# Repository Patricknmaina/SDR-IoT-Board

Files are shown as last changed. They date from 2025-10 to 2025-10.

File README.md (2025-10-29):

# SDR‑IoT‑Board

An IoT-based edge device and ground-station platform designed for telemetry and mission data—integrated with a 1U nanosatellite workflow. The hardware centers on an ESP32‑S3 module with LoRa, microSD storage, battery management/charging, sensor interfaces, and multiple expansion headers for rapid prototyping and deployment.

<p align="center">
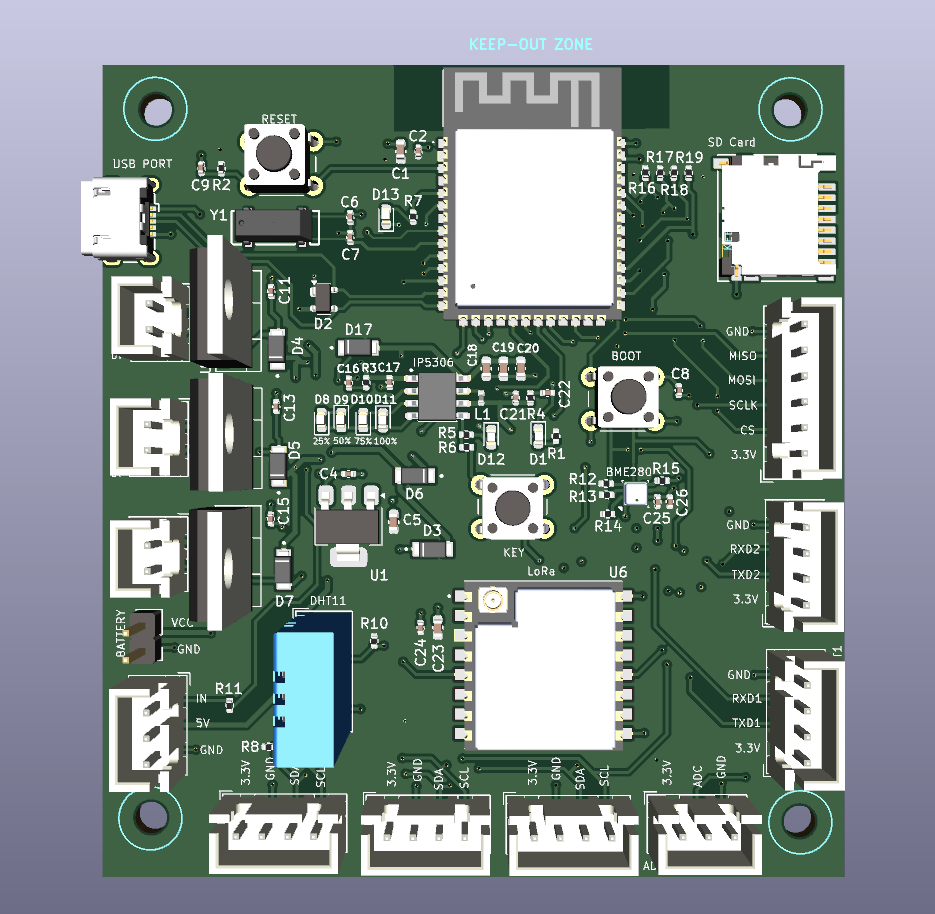
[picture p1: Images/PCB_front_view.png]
PCB Front
  
  <br/>
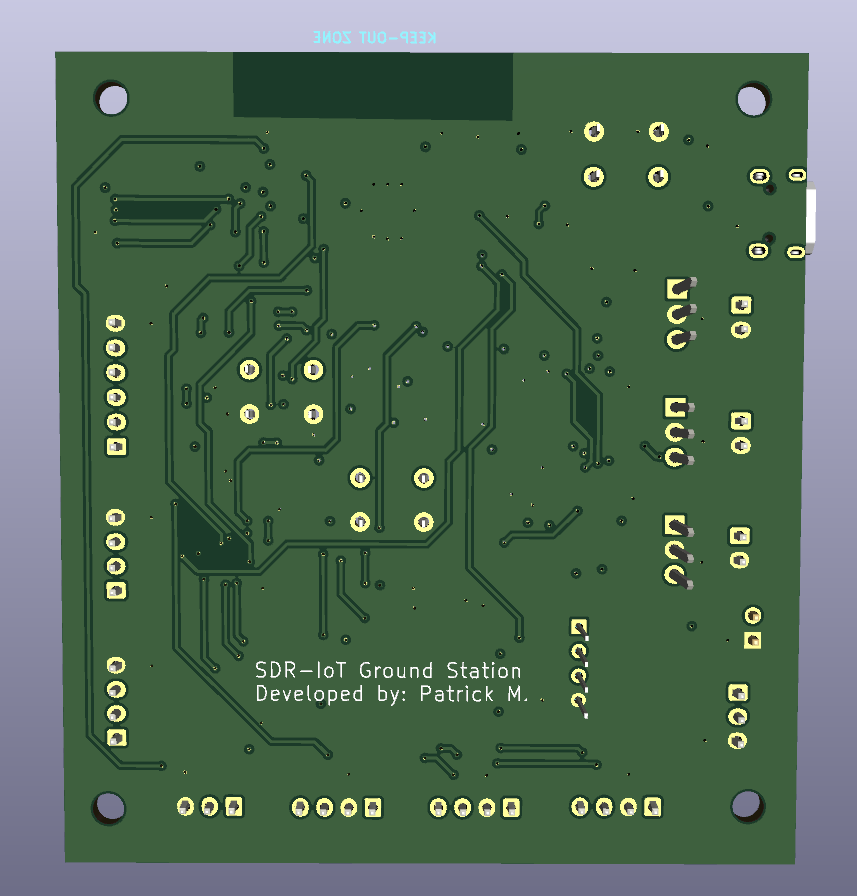
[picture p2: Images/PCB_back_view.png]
PCB Back
  
  <br/>
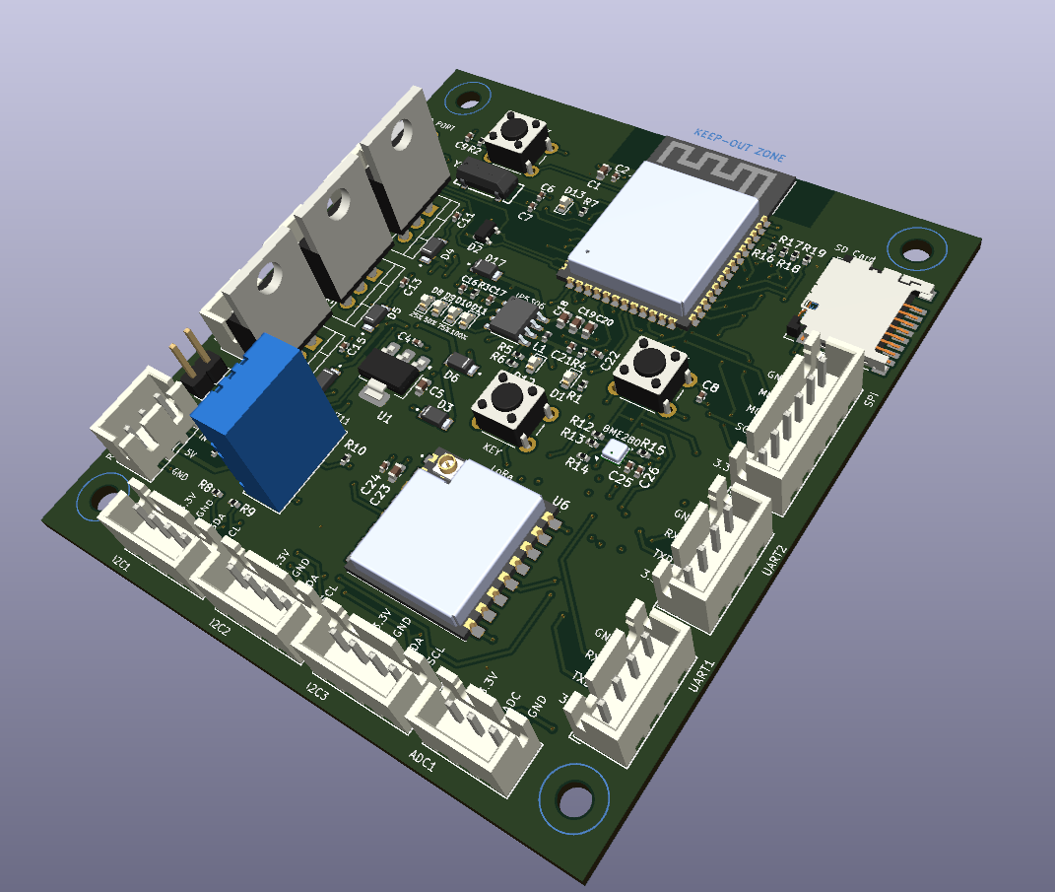
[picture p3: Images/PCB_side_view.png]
PCB Side
  
  <br/>
</p>

## Table of Contents

- Overview
- Key Features
- Hardware Architecture
- Power Architecture
- Interfaces and Connectors
- Major Components
- Project Structure
- Manufacturing (Gerbers, BOM, CPL)
- Bring‑Up Checklist
- Firmware Getting Started
- Mechanical and 3D Models
- License
- Acknowledgements and Notes

## Overview

This repository contains the complete KiCad design for the IoT Edge Device v1.0, including schematic, PCB layout, fabrication outputs, custom footprints, and mechanical models. No firmware is included in this repository; the board is intended to be programmed using the ESP32‑S3’s native USB interface (ESP‑IDF or Arduino‑ESP32).

Use cases include ground-station telemetry collection, environmental sensing, edge data logging, and LoRa-based long-range links to remote nodes or satellite payload testbeds.

## Key Features

- ESP32‑S3‑WROOM‑1‑N16R8 module (16 MB flash, 8 MB PSRAM)
- LoRa radio module (Ai‑Thinker RA‑02, SPI interface)
- microSD storage (SPI mode selected; design notes on SPI vs. SDIO)
- Environmental sensing: BME280 (I2C; default address 0x76), DHT11 header
- Multiple I2C expansion headers for quick peripheral add‑ons
- Two UART headers for serial peripherals and diagnostics
- Relay driver header (external 5 V relay module), driven via ESP32‑S3 GPIO6 through 1 kΩ
- Native USB (Micro‑B) with ESD protection for data and power
- Battery management/boost via IP5306 module; status LEDs for charge/level
- 3.3 V rail via AMS1117‑3.3 LDO
- 32.768 kHz RTC crystal for ESP32‑S3 (ESR ≤ 70 kΩ per note)

## Hardware Architecture

- Microcontroller: ESP32‑S3‑WROOM‑1‑N16R8 (`IoT Edge Device v1.0/IoT Edge Device V1.kicad_sch`)
- Radio: RA‑02 LoRa (SPI: `MOSI_LORA`, `MISO_LORA`, `SCLK_LORA`, `CS_LORA`)
- Storage: microSD (SPI: `MOSI_SD`, `MISO_SD`, `SCLK_SD`, `CS_SD`)
- Sensors: BME280 on I2C (SDO pulled Low → default 0x76), DHT11 via single‑wire `DHT_DATA` header
- Expansion: three I2C headers (`SCL_OUT`, `SDA_OUT`), SPI header, UART1/2 headers
- Control: Relay header driven from ESP32‑S3 GPIO6 via 1 kΩ current‑limit resistor
- Clocking: 32.768 kHz crystal for RTC; ensure ESR ≤ 70 kΩ
- Protection: SP05xxx ESD array on USB; Schottky diodes for power ORing

Notes
- Design text documents the choice of SPI over SDIO for simplicity (SDIO is faster but higher complexity/CPU tradeoffs).
- Exact ESP32 GPIO mappings for the above nets are defined in the schematic; see the KiCad file for authoritative pinout and update firmware pin definitions accordingly.

## Power Architecture

- Sources: 5 V via USB Micro‑B and from IP5306 boost output; diode‑OR prevents back‑feeding.
- Solar input: 12 V panel → external LM7805 module → 5 V for IP5306 input (see design note). For higher efficiency and thermal margin, a buck regulator is recommended over linear.
- Battery: IP5306 manages charging and provides 5 V output; LED indicators for charge and capacity.
- 3.3 V rail: AMS1117‑3.3 LDO powers ESP32‑S3, LoRa, and sensors.

Recommendations
- Consider replacing the 12 V→5 V LM7805 path with a high‑efficiency buck (e.g., LM2596/MP1584) to reduce heat and increase battery/runtime performance.
- Validate 3.3 V load headroom (ESP32‑S3 + LoRa TX + SD activity) and thermal dissipation for the LDO.

## Interfaces and Connectors

- USB: Micro‑B connector; native ESP32‑S3 USB (D+ / D−) for flashing and CDC; ESD protection present.
- I2C: labeled I2C1 / I2C2 / I2C3 headers on `SCL_OUT` and `SDA_OUT` nets.
- SPI: dedicated header labeled “SPI Connector”.
- UART: UART1 and UART2 headers; UART2 noted for DAC use case.
- Relay: external 5 V relay module header; controlled by ESP32‑S3 GPIO6 via 1 kΩ series resistor.
- SD Card: microSD socket (SPI wiring).
- LoRa: RA‑02 module (SPI wiring with dedicated CS).

## Major Components

- X1: ESP32‑S3‑WROOM‑1‑N16R8 (MCU + Wi‑Fi/BLE, native USB)
- U6: Ai‑Thinker RA‑02 LoRa module (SPI)
- J15: microSD socket (Hirose DM3D‑SF)
- U8: BME280 environmental sensor (I2C, default 0x76)
- DHT11: external module via header (`DHT_DATA`)
- U5: IP5306 battery charger/boost controller
- U1: AMS1117‑3.3 linear regulator
- J1: USB Micro‑B connector
- D2: SP05xxx ESD protection for USB
- D4–D7: DFLS130L‑7 Schottky diodes (power ORing)
- Y1: 32.768 kHz crystal for RTC

See `IoT Edge Device v1.0/Fab Files/IoT BOM.csv` for the full sourced BOM (with JLCPCB part numbers) and `IoT Edge Device v1.0/Fab Files/IoT CPL.csv` for centroid/placements.

## Project Structure

- `IoT Edge Device v1.0/` — KiCad project (schematic, PCB, project metadata)
  - `IoT Edge Device V1.kicad_sch` — Schematic
  - `IoT Edge Device V1.kicad_pcb` — PCB layout
  - `Fab Files/` — Gerbers, drill, BOM, CPL for fabrication and assembly
  - `Fabrication Outputs.zip` — Consolidated fab package
- `Design Resources/` — Custom footprints and STEP models
- `Images/` — Renders and module screenshots used in this README

## Manufacturing (Gerbers, BOM, CPL)

All files required for fab and assembly are provided:

1) Gerbers and Drill
- Path: `IoT Edge Device v1.0/Fab Files/*gbr`, `.../IoT Edge Device V1.drl`

2) Bill of Materials
- Path: `IoT Edge Device v1.0/Fab Files/IoT BOM.csv` (includes JLCPCB part numbers)

3) Pick & Place (Centroid)
- Path: `IoT Edge Device v1.0/Fab Files/IoT CPL.csv` (Top placements)

## Firmware Getting Started

- Toolchains: ESP‑IDF (v5.x) or Arduino‑ESP32 with S3 support
- Transport: Native USB (CDC) for flashing and serial output
- Pin definitions: Map nets from the schematic to firmware pins:
  - LoRa SPI: `MOSI_LORA`, `MISO_LORA`, `SCLK_LORA`, `CS_LORA`
  - SD SPI: `MOSI_SD`, `MISO_SD`, `SCLK_SD`, `CS_SD`
  - I2C: `SDA_OUT`, `SCL_OUT`
  - DHT11: `DHT_DATA`
  - Relay: `GPIO6`

Since the ESP32 GPIO numbers tied to these nets can vary by routing, use the KiCad schematic (`.kicad_sch`) as the source of truth and set your firmware `gpio_num_t` values accordingly.

Libraries
- LoRa: `arduino-lmic` or `RadioLib` (Arduino), or ESP‑IDF SPI drivers with Semtech HAL equivalents
- microSD: `SD`/`SdFat` (Arduino) or ESP‑IDF `sdspi_host`
- BME280: Adafruit/ESP‑IDF drivers (I2C)
- DHT11: Adafruit (Arduino) or a simple single‑wire driver

## Mechanical and 3D Models

- STEP models for key parts are under `Design Resources/STEP Files/` (ESP32‑S3 module, RA‑02, IP5306, microSD, crystal, etc.)
- Use these for enclosure fit, heatsinking studies, and cable clearance.

## License

This project is released under the MIT License. See `LICENSE` for details.

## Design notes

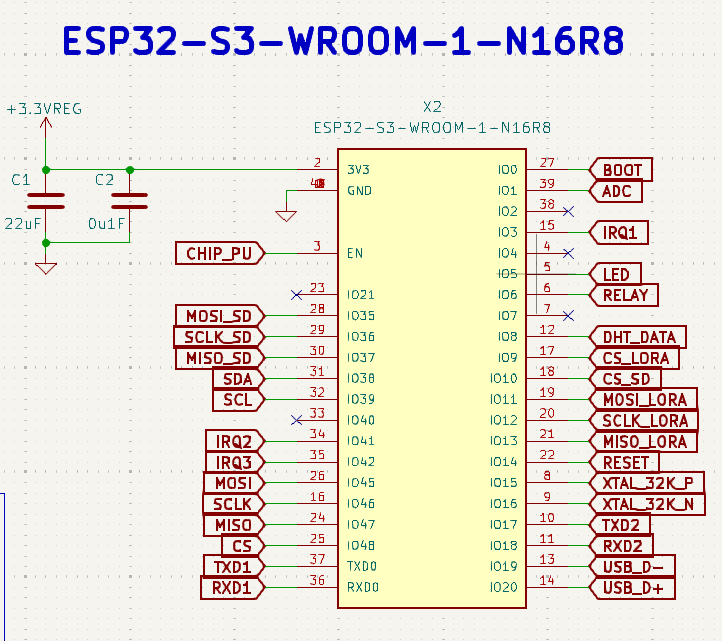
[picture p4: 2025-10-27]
Images/ESP32-S3_module.png

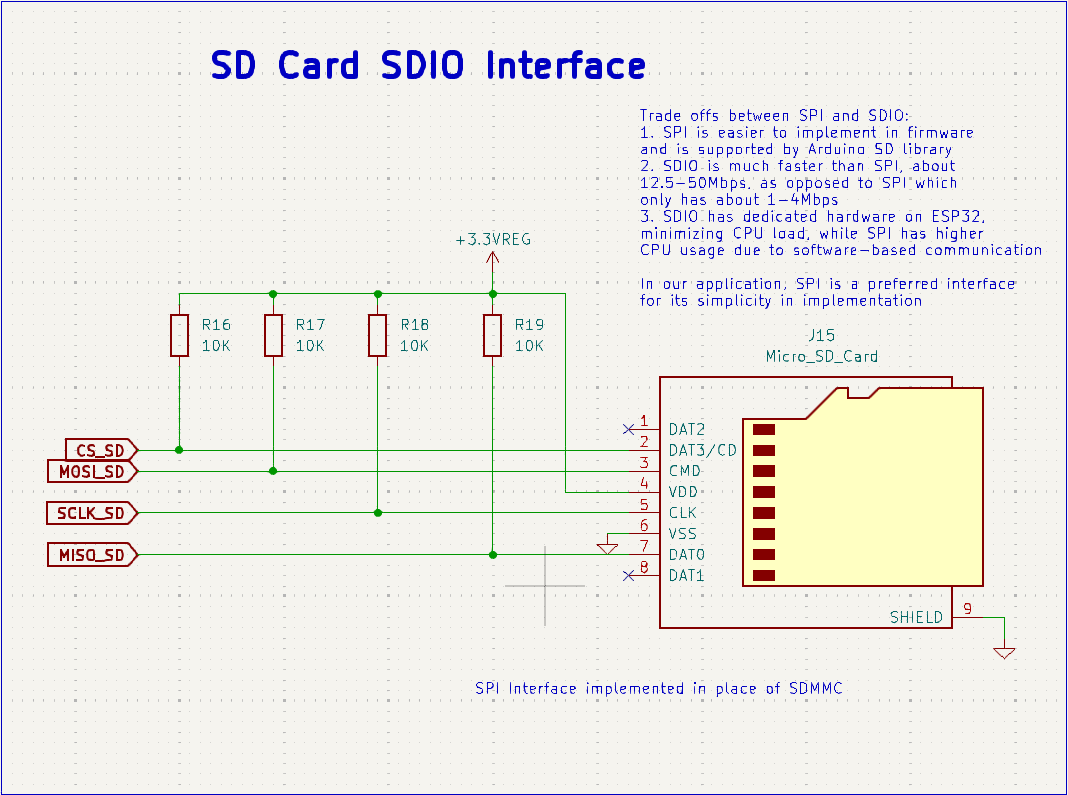
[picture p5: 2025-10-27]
Images/SD-Card_module.png

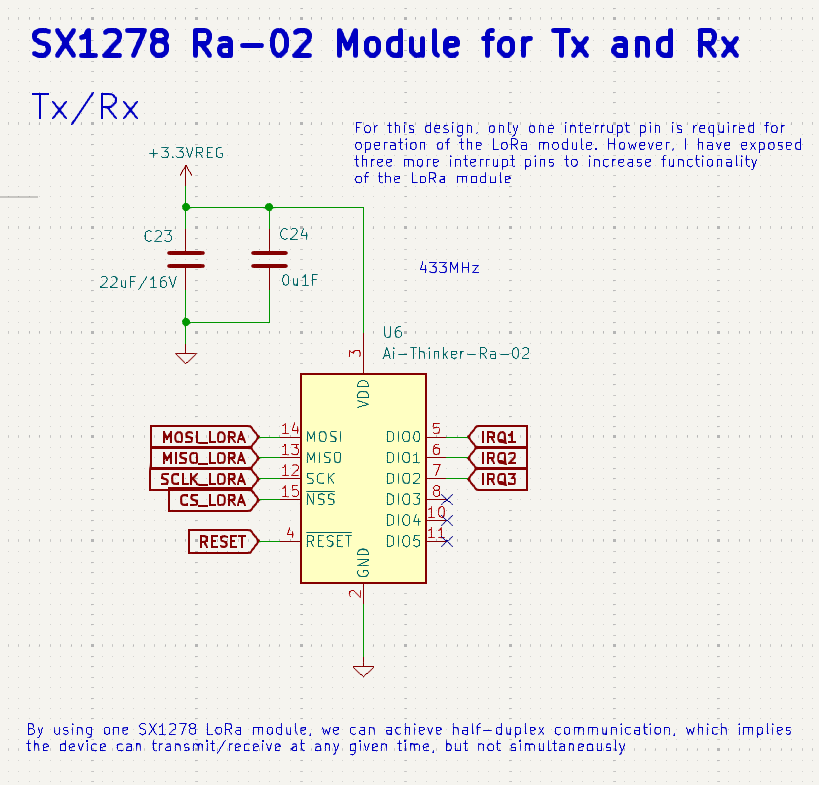
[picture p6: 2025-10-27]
Images/lora_module.png

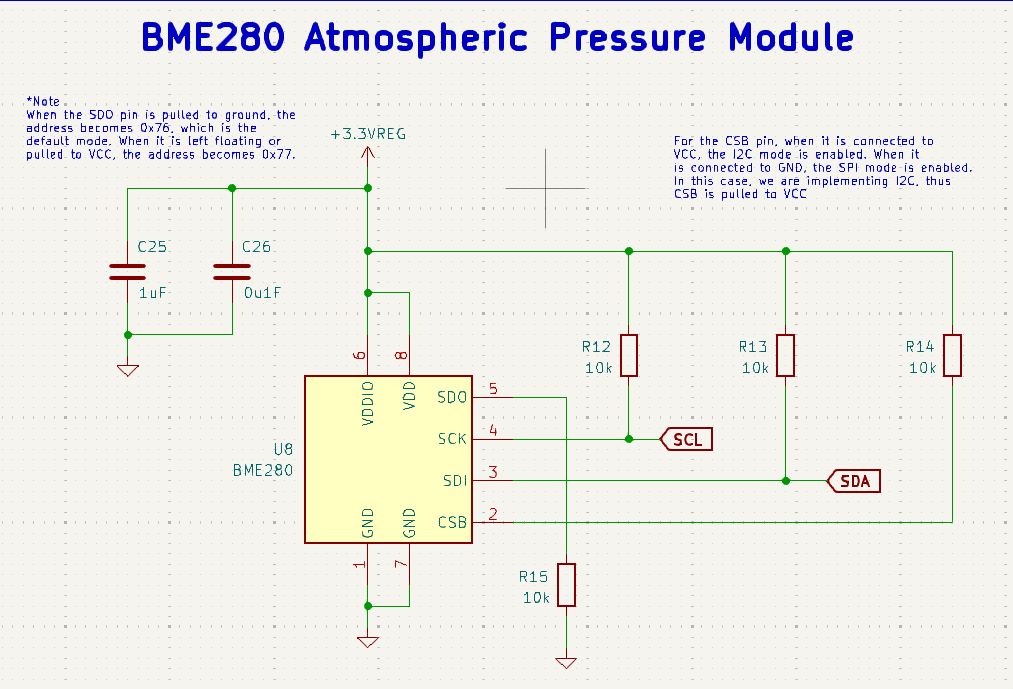
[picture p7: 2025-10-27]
Images/BME280_module.png

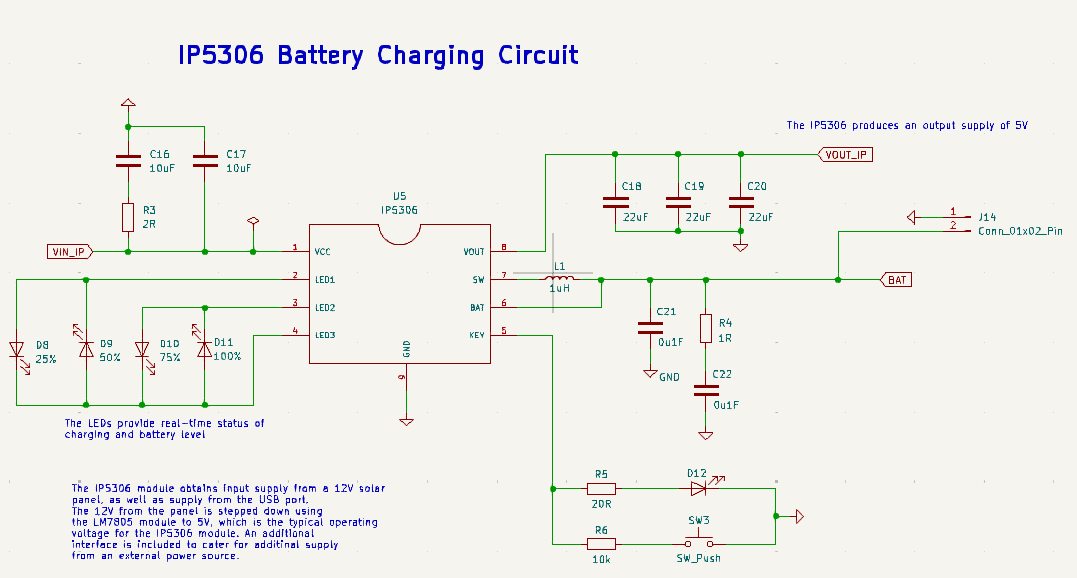
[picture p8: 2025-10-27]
Images/IP5306_module.png

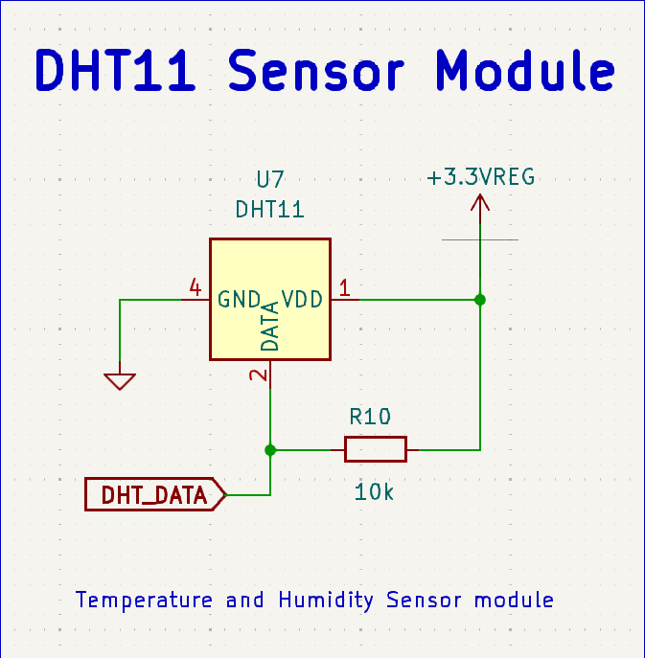
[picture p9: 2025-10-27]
Images/DHT11_module.png

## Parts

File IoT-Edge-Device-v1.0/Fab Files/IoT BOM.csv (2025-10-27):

Comment | Designator | Footprint | JLCPCB Part #
22uF Unpolarized capacitor | C1,C5,C18,C19,C20 | Capacitor_SMD:C_0603_1608Metric | C59461
0.1uF Unpolarized capacitor | C2,C8,C9,C11,C13,C15,C21,C22,C24,C26 | Capacitor_SMD:C_0402_1005Metric | C14663
1uF Unpolarized capacitor | C3,C25 | Capacitor_SMD:C_0402_1005Metric | C15849
10uF Unpolarized capacitor | C4,C16,C17 | Capacitor_SMD:C_0402_1005Metric | C19702
10pF Unpolarized capacitor | C6,C7 | Capacitor_SMD:C_0402_1005Metric | C1634
0.33uF Unpolarized capacitor | C10,C12,C14 | Capacitor_SMD:C_0402_1005Metric | C3039642
22uF/16V Unpolarized capacitor | C23 | Capacitor_SMD:C_0603_1608Metric | C5116073
Red Power Light emitting diode (LED) | D1 | LED_SMD:LED_0603_1608Metric | C965799
Blue IP5306 Key Status LED | D12 | LED_SMD:LED_0603_1608Metric | C965807
Green Status LED | D13 | LED_SMD:LED_0603_1608Metric | C22371297
SP0503BAHT TVS Diode Array, 5.5V Standoff, 3 Channels, SOT-143 package | D2 | Package_TO_SOT_SMD:SOT-143 | C7074
DFLS130L-7 | D4,D5,D6,D7 | DFLS130L-7:DIO_DFLS130L-7 | C110493
25%, 50%, 75% Light emitting diode (Red) | D8, D9, D10 | LED_SMD:LED_0603_1608Metric | C965799
100% Light emitting diode (Green) | D11 | LED_SMD:LED_0603_1608Metric | C22371297
1000V 1A General Purpose Rectifier Diode, DO-41 | D14 | Diode_SMD:D_0603_1608Metric | C727081
Relay Green Status LED | D15 | LED_SMD:LED_0603_1608Metric | C22371297
Relay Red Power LED | D16 | LED_SMD:LED_0603_1608Metric | C965799
USB Micro Type B connector | J1 | Connector_USB:USB_Micro-B_Wuerth_629105150521 | C2894326
Micro SD Card Socket | J15 | Connector_Card:microSD_HC_Hirose_DM3D-SF | C719027
1uH Inductor | L1 | Inductor_SMD:L_0402_1005Metric | C531288
1k Resistor | R1,R4,R5,R15,R16,R17,R18 | Resistor_SMD:R_0402_1005Metric | C11702
10k Resistor | R2,R3,R9,R10,R11,R12,R13,R14,R19,R20,R21,R22 | Resistor_SMD:R_0402_1005Metric | C25744
2R Resistor | R6 | Resistor_SMD:R_0402_1005Metric | C2906922
1R Resistor | R7 | Resistor_SMD:R_0402_1005Metric | C137904
20R Resistor | R8 | Resistor_SMD:R_0402_1005Metric | C310214
1A Low Dropout regulator, positive, 3.3V fixed output, SOT-223 (AMS1117-3.3) | U1 | Package_TO_SOT_SMD:SOT-223-3_TabPin2 | C347222
Ai-Thinker Ra-02 410-525 MHz LoRa Module, SPI interface, U.FL antenna connector | U6 | RA-02_LORA:MODULE_RA-02_LORA | C90039
3-in-1 sensor, humidity, pressure, temperature, I2C and SPI interface, 1.71-3.6V, LGA-8 (BME280) | U8 | Package_LGA:Bosch_LGA-8_2.5x2.5mm_P0.65mm_ClockwisePinNumbering | C92489
IP5306 | U5 | IP5306:SOIC9P127_490X600X170L84X42T330X241N | C181692
ESP32-S3-WROOM-1-N16R8 Module | X1 | ESP32-S3-WROOM-1-N16R8:ESP32S3WROOM1N8R2 | C2913202
WE-XTAL-85SMX Crystal Oscillator | Y1 | WE-XTAL_85SMX:WE-XTAL_85SMX | N/A

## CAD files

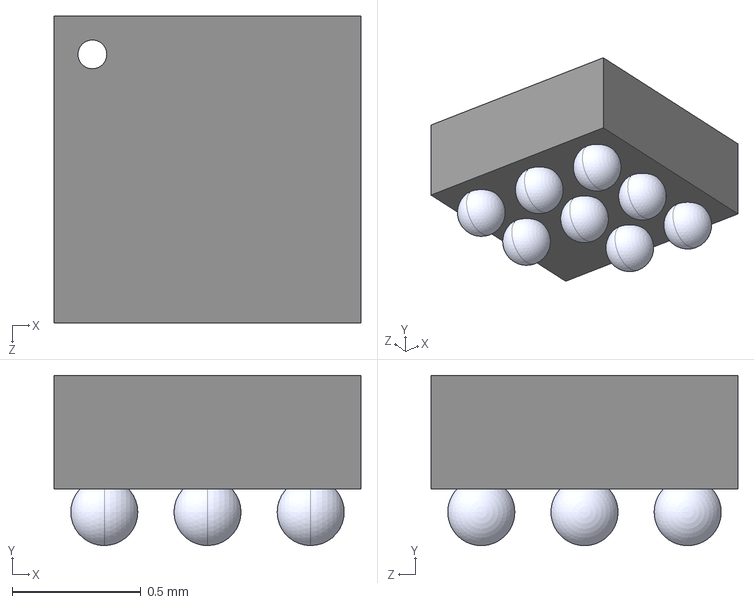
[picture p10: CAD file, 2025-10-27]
Design Resources/Footprints/IP5306/IP5306.step
1.19 x 0.66 x 1.19 mm

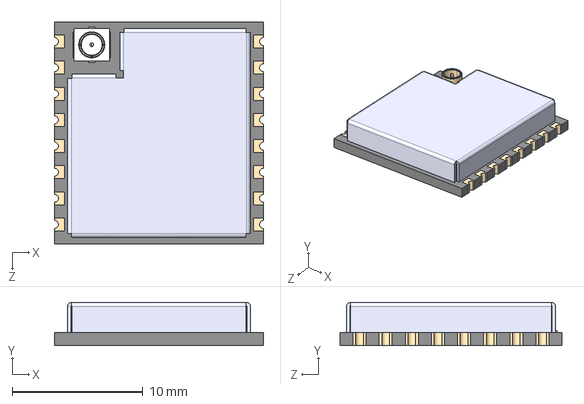
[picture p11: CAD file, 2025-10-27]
Design Resources/STEP Files/RA-02_LORA.step
16.0 x 3.30 x 17.0 mm

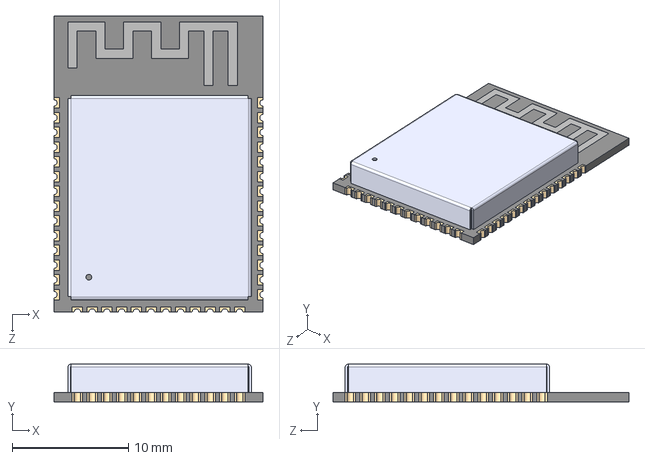
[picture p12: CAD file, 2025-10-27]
Design Resources/STEP Files/ESP32-S3-WROOM-1-N16R8.step
18.0 x 3.25 x 25.5 mm

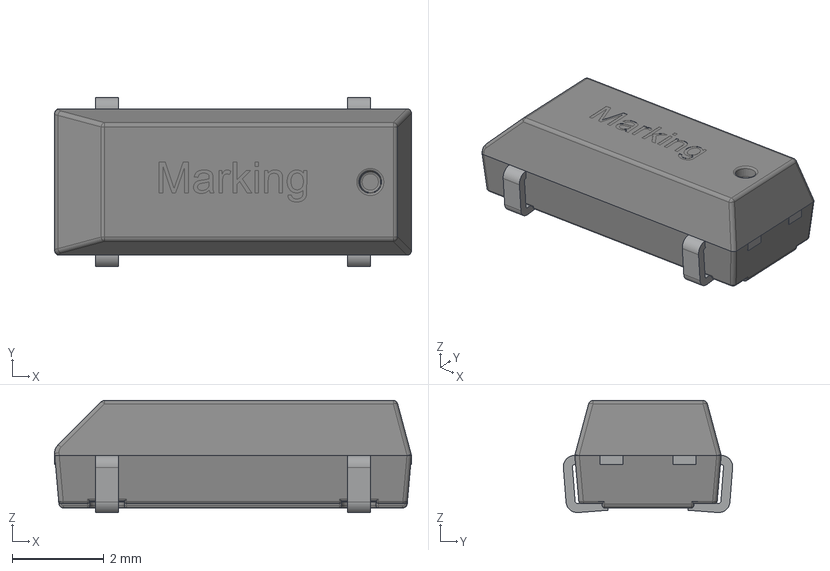
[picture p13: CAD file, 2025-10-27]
Design Resources/STEP Files/WE-XTAL_85SMX.step
7.80 x 3.70 x 2.45 mm
Base
TopCover
Pin

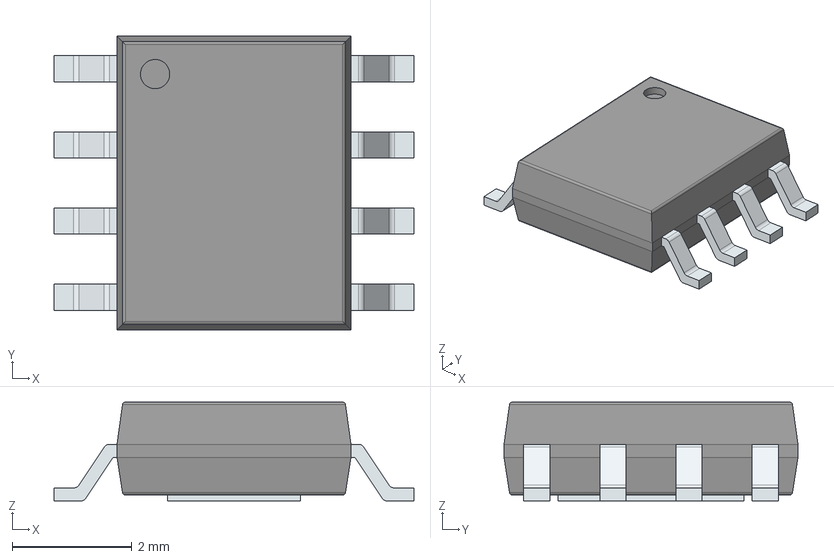
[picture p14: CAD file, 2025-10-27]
Design Resources/STEP Files/IP5306.stp
6.00 x 4.90 x 1.65 mm
PinsArrayLR
ThermalPad

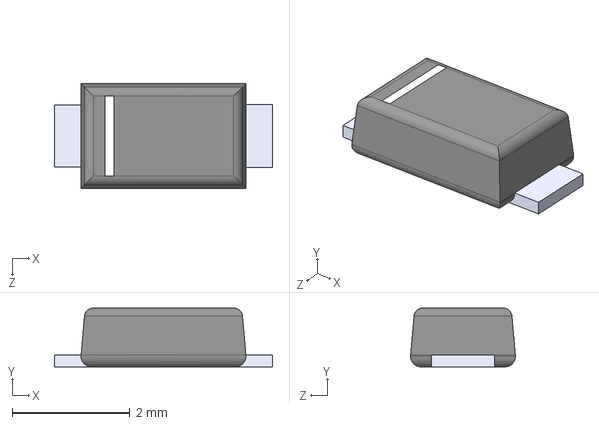
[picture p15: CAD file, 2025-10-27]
Design Resources/STEP Files/DFLS130L-7.step
3.70 x 1.00 x 1.78 mm

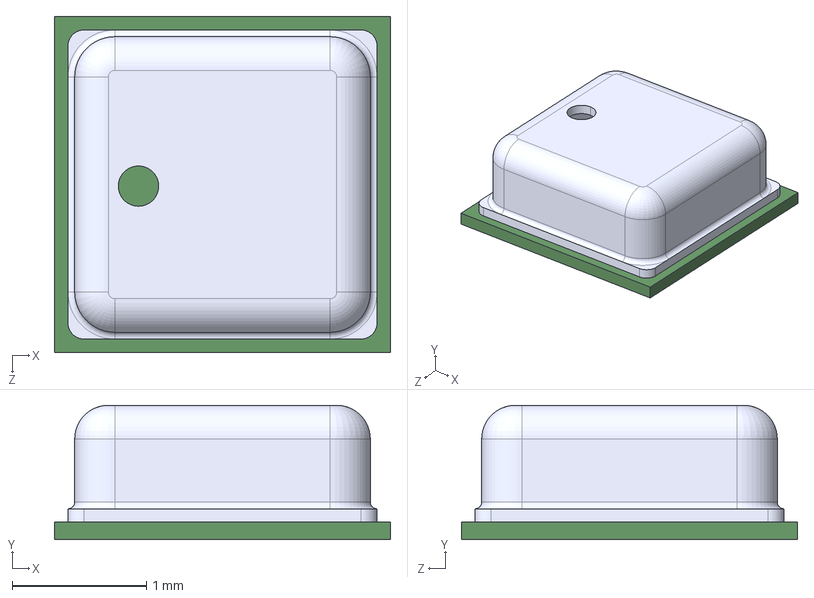
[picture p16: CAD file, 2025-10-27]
Design Resources/STEP Files/BME280--3DModel-STEP-56544.STEP
2.50 x 1.00 x 2.50 mm

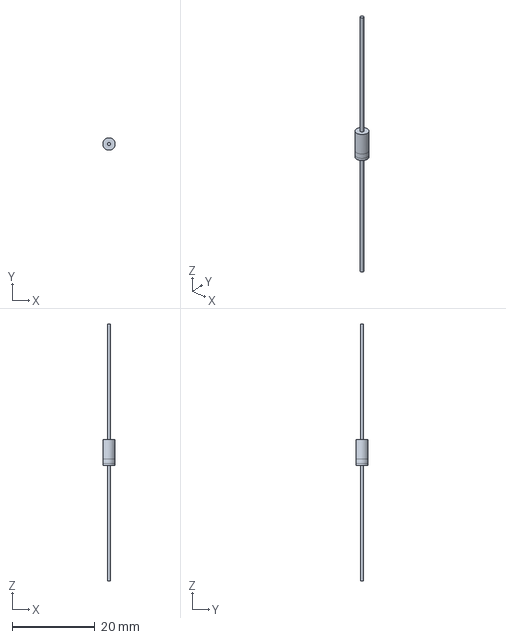
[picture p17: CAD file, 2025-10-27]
Design Resources/STEP Files/1N5819.STEP
3.00 x 3.00 x 62.0 mm

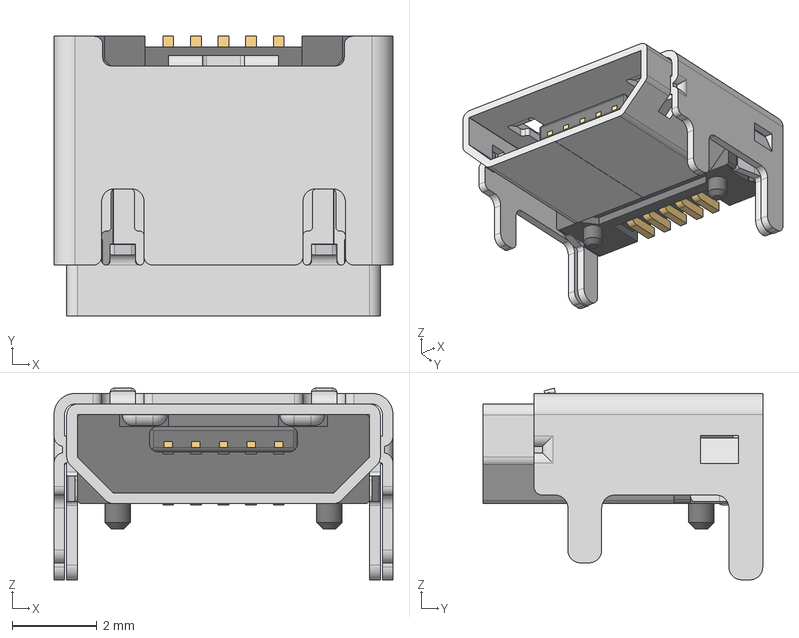
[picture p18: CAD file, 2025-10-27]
Design Resources/STEP Files/62910515021_USB_Micro_B.stp
8.00 x 6.60 x 4.52 mm
629105150521_Housing
629105150521_Pin1 x 4
629105150521_Pin2
629105150521_Shielding2
629105150521_Shielding

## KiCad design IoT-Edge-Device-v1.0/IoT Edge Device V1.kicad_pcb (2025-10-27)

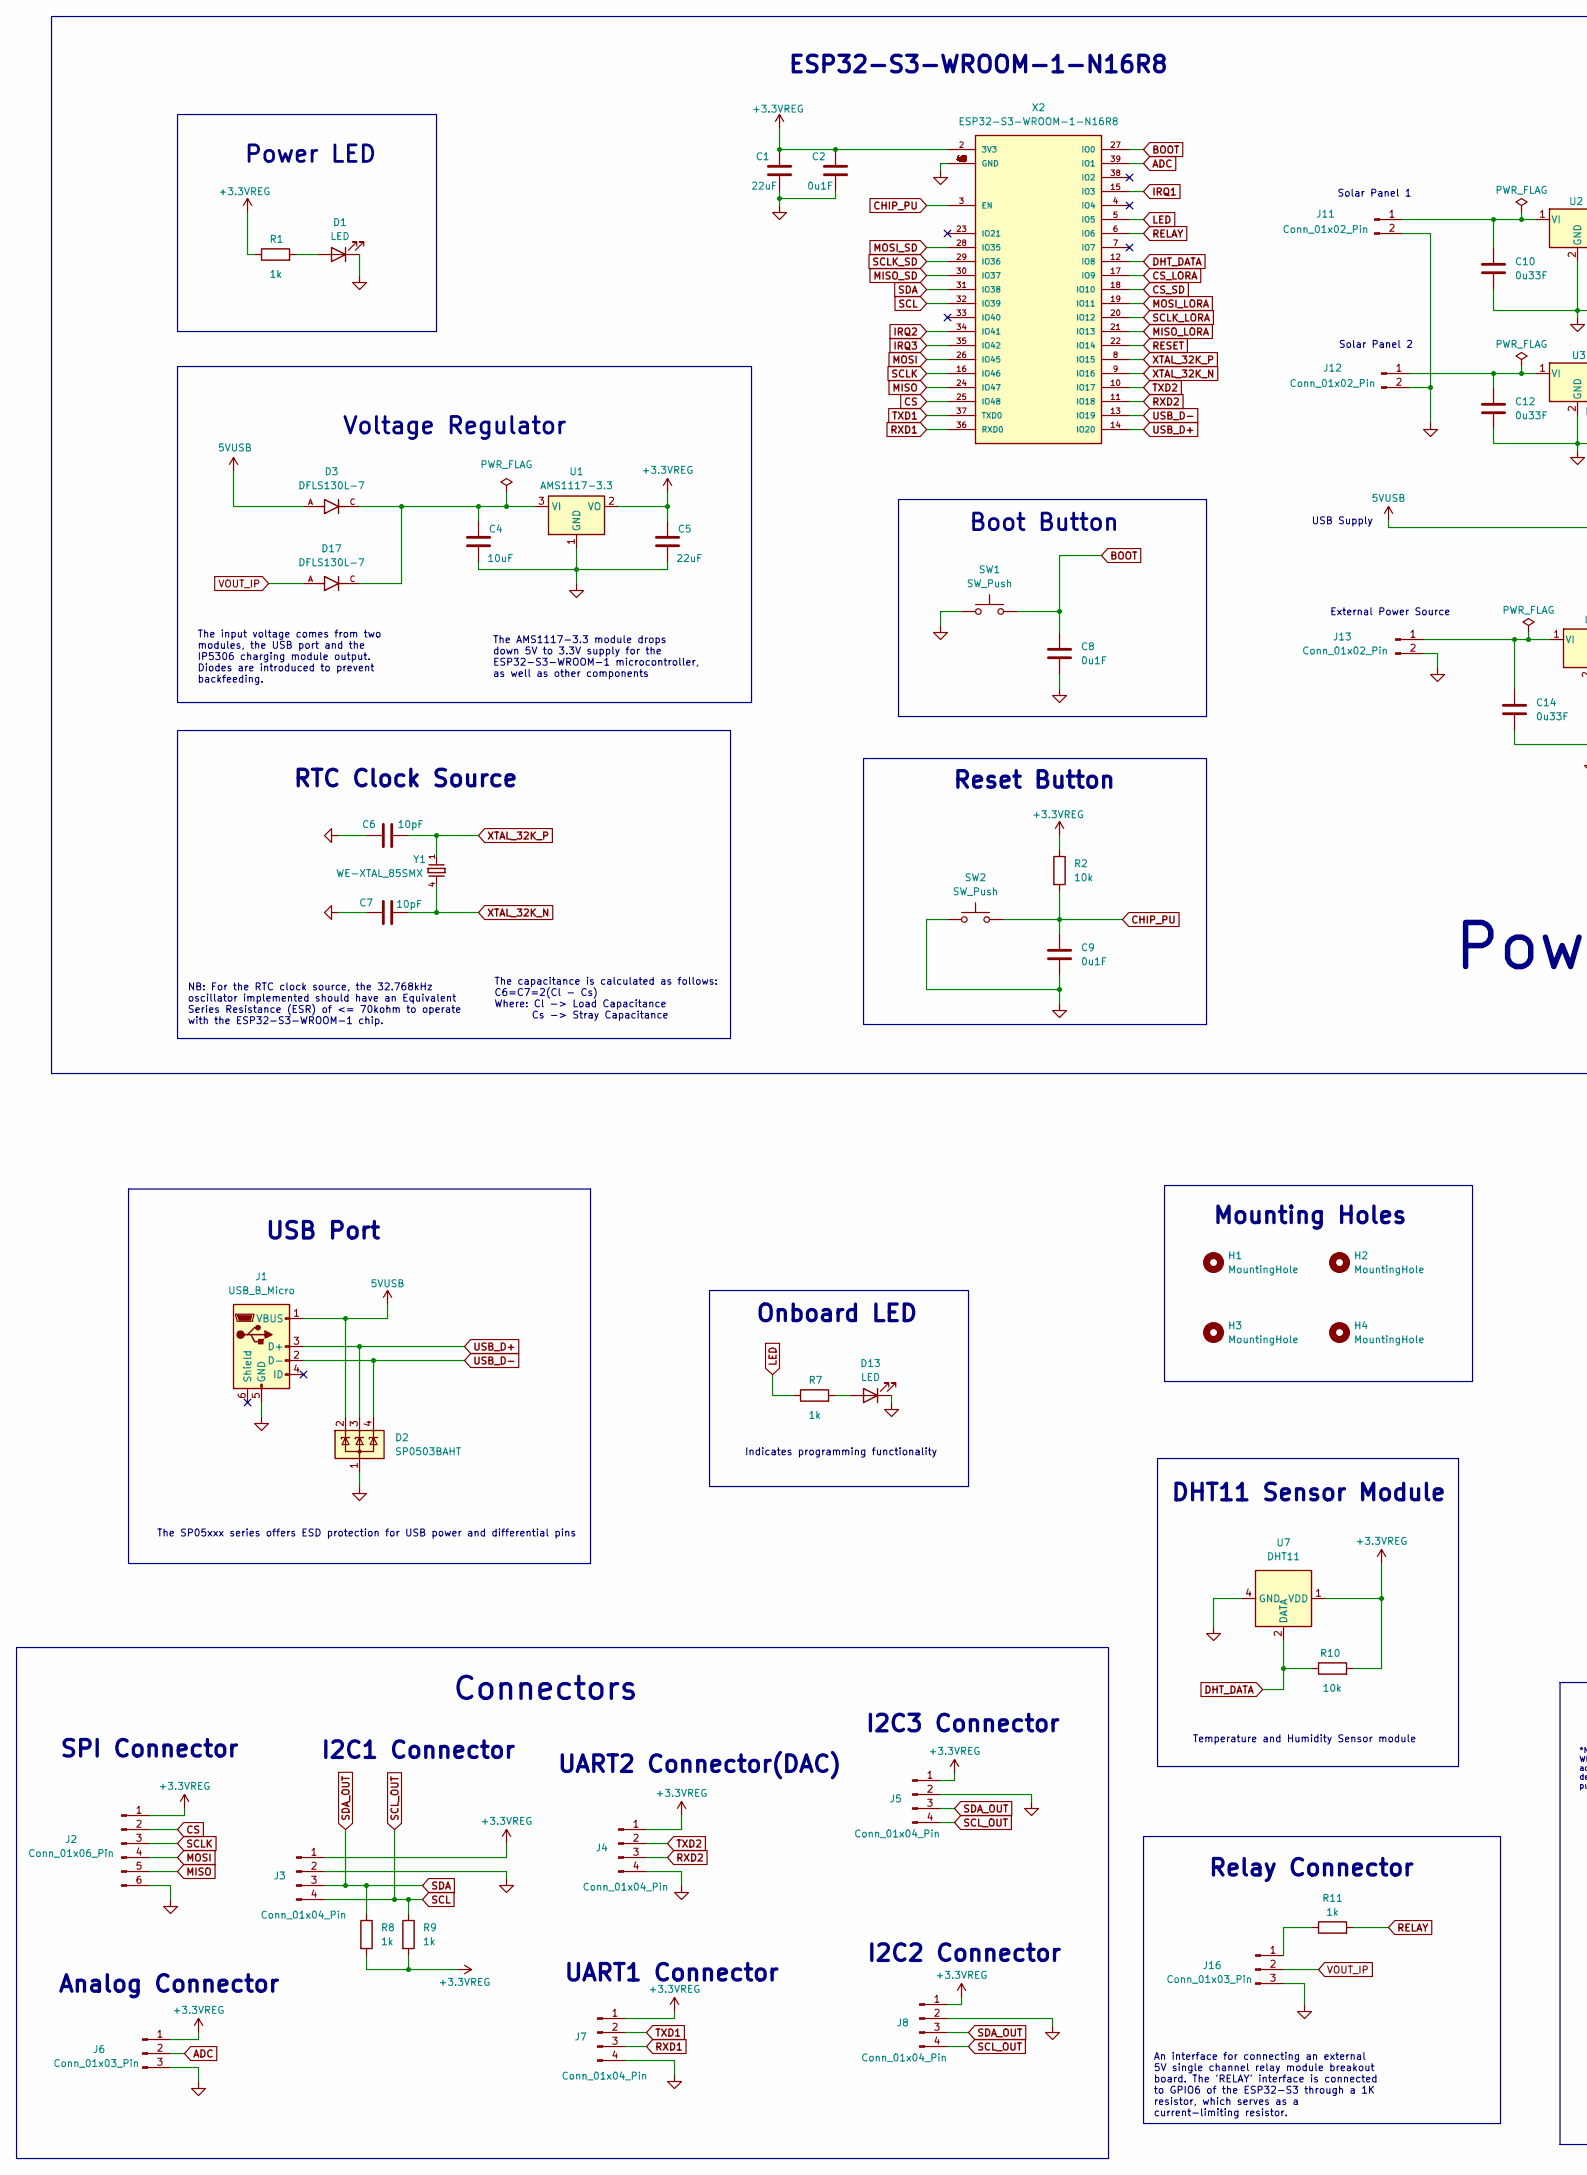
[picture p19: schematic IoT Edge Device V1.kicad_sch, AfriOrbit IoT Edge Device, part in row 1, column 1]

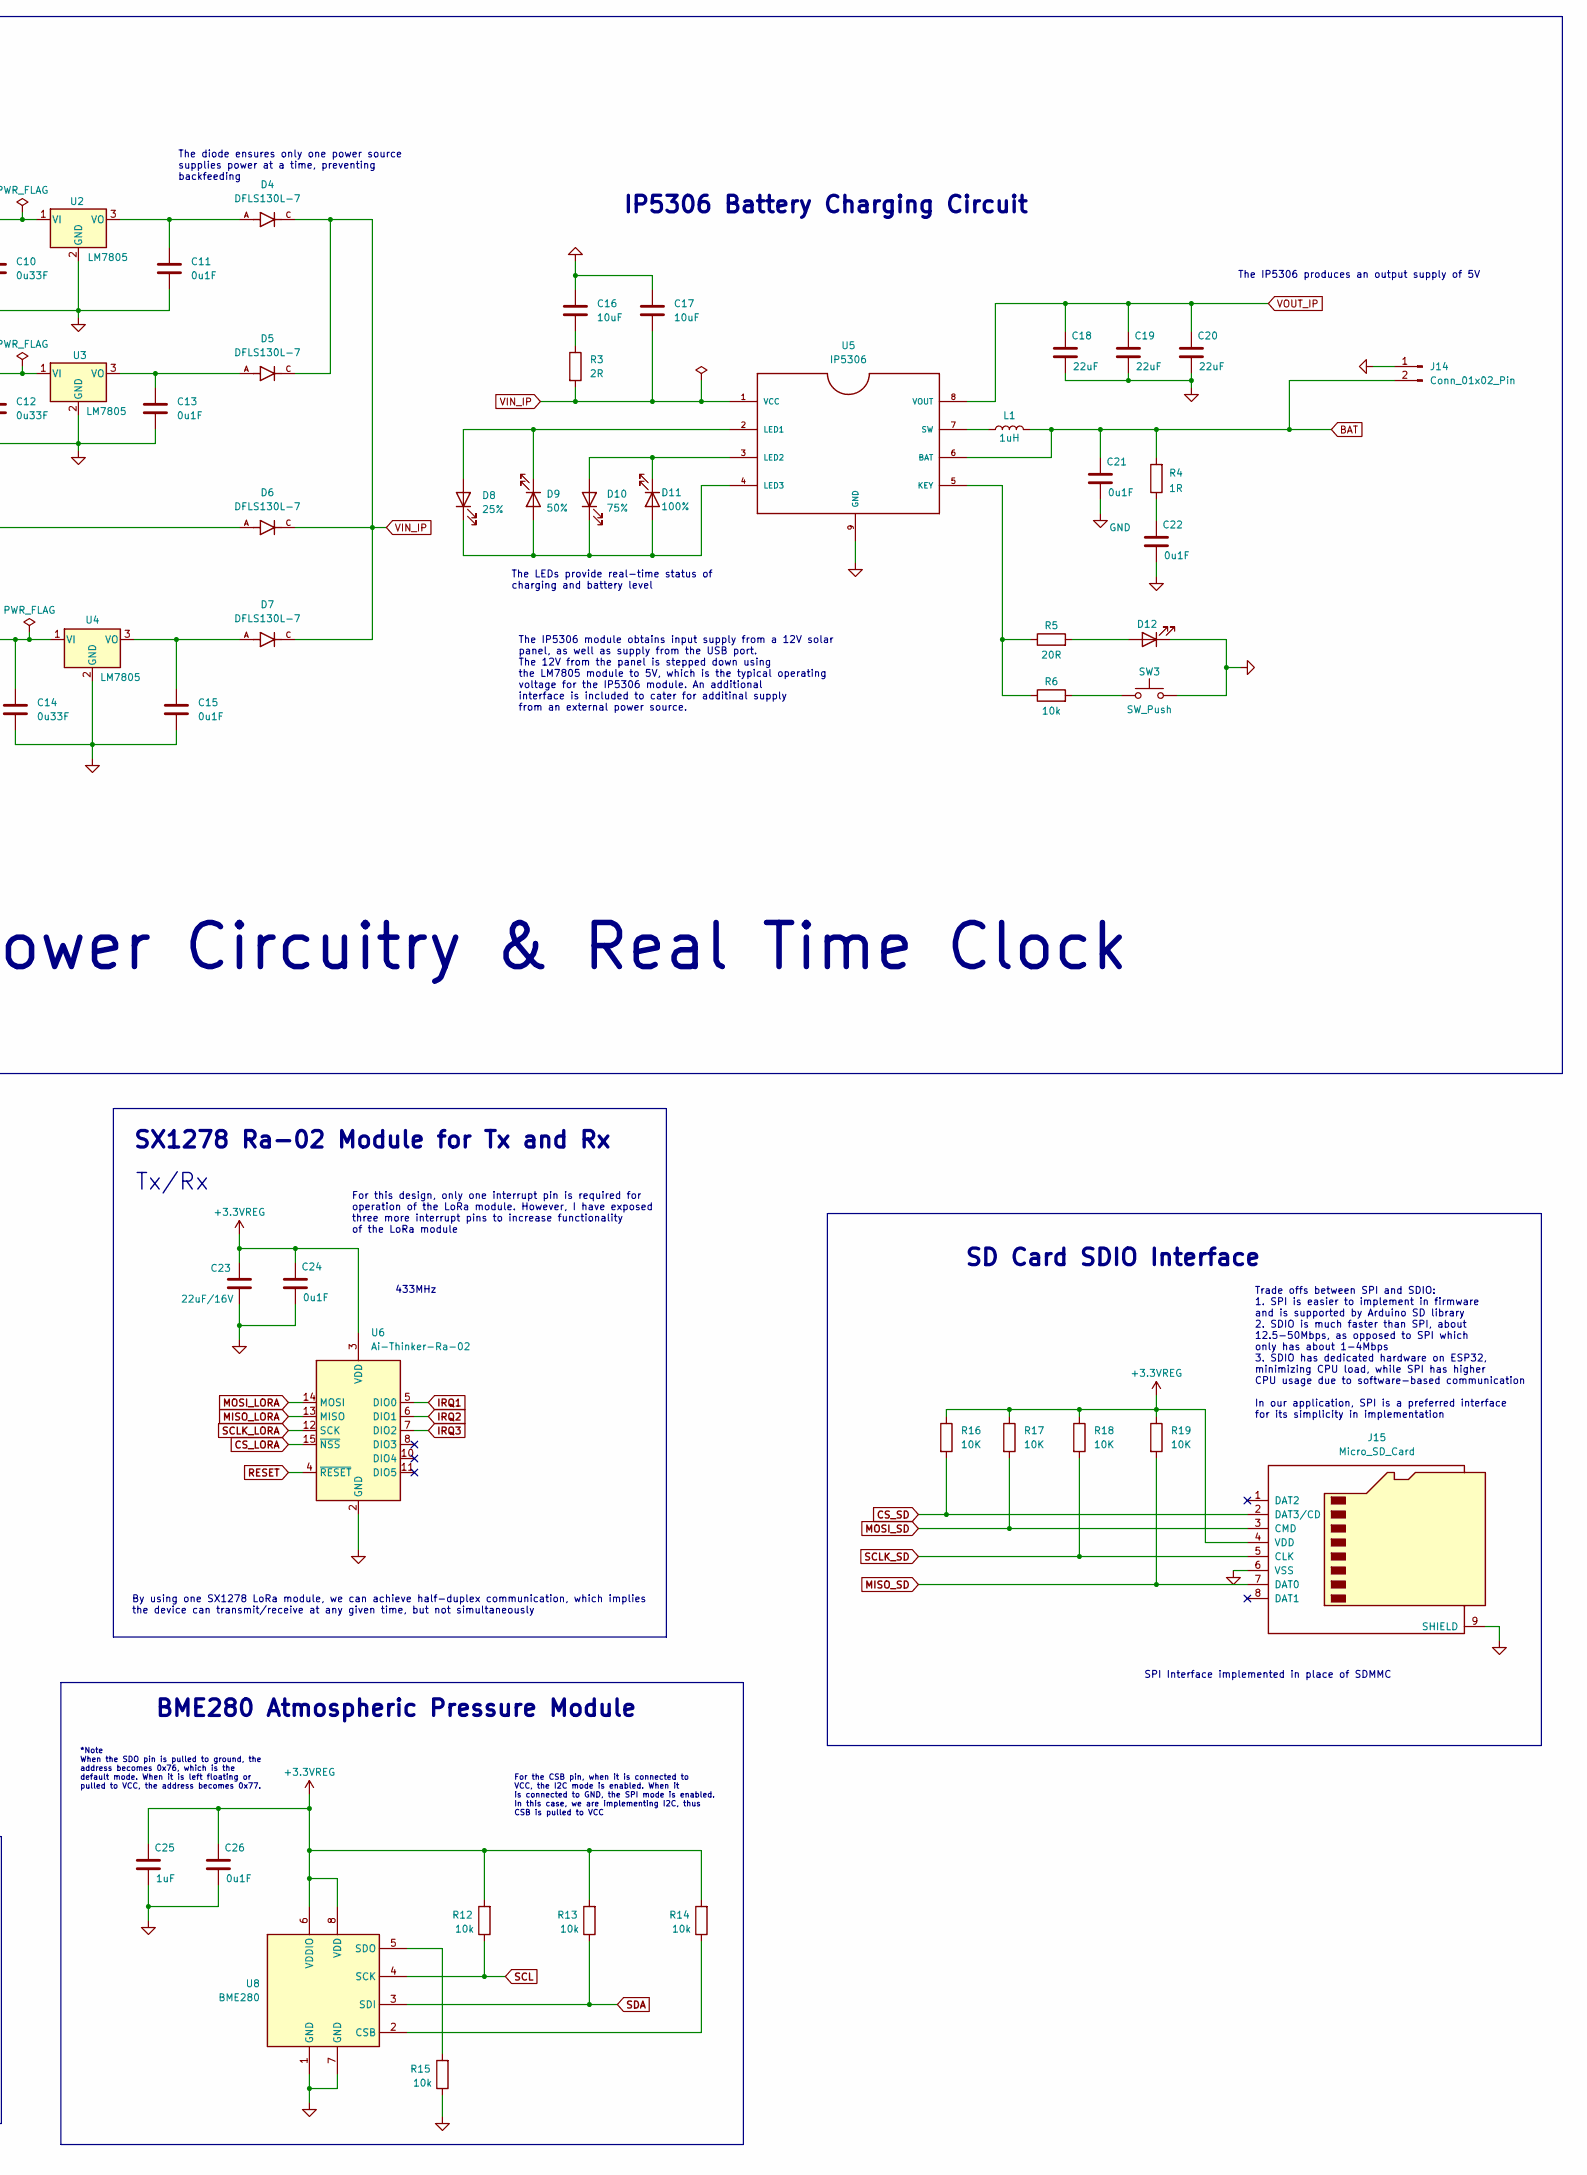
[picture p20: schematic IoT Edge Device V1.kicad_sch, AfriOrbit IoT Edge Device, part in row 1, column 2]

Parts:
C1, C5, C18, C19, C20: 22uF; C_0603_1608Metric
C2, C8, C9, C11, C13, C15, C21, C22, C24, C26: 0u1F; C_0402_1005Metric
C4, C16, C17: 10uF; C_0402_1005Metric
C6, C7: 10pF; C_0402_1005Metric
C10, C12, C14: 0u33F; C_0402_1005Metric
C23: 22uF/16V; C_0603_1608Metric
C25: 1uF; C_0402_1005Metric
D1, D12, D13: LED; LED_0603_1608Metric
D2: SP0503BAHT; SOT-143
D3, D4, D5, D6, D7, D17: DFLS130L-7; DIO_DFLS130L-7; PARTREV 5 - 2
D8: 25%; LED_0603_1608Metric
D9: 50%; LED_0603_1608Metric
D10: 75%; LED_0603_1608Metric
D11: 100%; LED_0603_1608Metric
H1, H2, H3, H4: MountingHole; MountingHole_3.2mm_M3
J1: USB_B_Micro; USB_Micro-B_Wuerth_629105150521
J2: Conn_01x06_Pin; JST_XH_B6B-XH-A_1x06_P2.50mm_Vertical
J3, J4, J5, J7, J8: Conn_01x04_Pin; JST_XH_B4B-XH-A_1x04_P2.50mm_Vertical
J6, J16: Conn_01x03_Pin; JST_XH_B3B-XH-A_1x03_P2.50mm_Vertical
J11, J12, J13: Conn_01x02_Pin; JST_XH_B2B-XH-A_1x02_P2.50mm_Vertical
J14: Conn_01x02_Pin; PinHeader_1x02_P2.54mm_Vertical
J15: Micro_SD_Card; microSD_HC_Hirose_DM3D-SF
L1: 1uH; L_0402_1005Metric
R1, R7, R8, R9, R11: 1k; R_0402_1005Metric
R2, R6, R10, R12, R13, R14, R15: 10k; R_0402_1005Metric
R3: 2R; R_0402_1005Metric
R4: 1R; R_0402_1005Metric
R5: 20R; R_0402_1005Metric
R16, R17, R18, R19: 10K; R_0402_1005Metric
SW1, SW2, SW3: SW_Push; SW_PUSH_6mm
U1: AMS1117-3.3; SOT-223-3_TabPin2
U2, U3, U4: LM7805; TO-220-3_Vertical
U5: IP5306; SOIC9P127_490X600X170L84X42T330X241N
U6: Ai-Thinker-Ra-02; MODULE_RA-02_LORA
U7: DHT11; Aosong_DHT11_5.5x12.0_P2.54mm
U8: BME280; Bosch_LGA-8_2.5x2.5mm_P0.65mm_ClockwisePinNumbering
X2: ESP32-S3-WROOM-1-N16R8; ESP32S3WROOM1N8R2; MANUFACTURER_PART_NUMBER ESP32-S3-WROOM-1-N16R8
Y1: WE-XTAL_85SMX

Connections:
5VUSB: D2.2 (K), D3.A, D6.A, J1.1 (VBUS)
+3.3VREG: C1.1, C2.1, C5.1, C23.1, C24.1, C25.1, C26.1, J2.1, J3.1, J4.1, J5.1, J6.1, J7.1, J8.1, J15.4 (VDD), R1.1, R2.1, R8.2, R9.2, R10.2, R12.2, R13.2, R14.2, R16.1, R17.1, R18.1, R19.1, U1.2 (VO), U6.3 (VDD), U7.1 (VDD), U8.6 (VDDIO), U8.8 (VDD), X2.2 (3V3); also elsewhere on the board
ADC: J6.2, X2.39 (IO1); also elsewhere on the board
BAT: C21.1, J14.2, L1.2, R4.2, U5.6 (BAT)
BOOT: C8.1, SW1.2, X2.27 (IO0); also elsewhere on the board
CHIP_PU: C9.1, R2.2, SW2.2, X2.3 (EN); also elsewhere on the board
CS: J2.2, X2.25 (IO48); also elsewhere on the board
CS_LORA: U6.15 (~NSS), X2.17 (IO9); also elsewhere on the board
CS_SD: J15.2 (DAT3/CD), R16.2, X2.18 (IO10); also elsewhere on the board
DHT_DATA: R10.1, U7.2 (DATA), X2.12 (IO8); also elsewhere on the board
GND: C1.2, C2.2, C4.2, C5.2, C6.1, C7.1, C8.2, C9.2, C10.2, C11.2, C12.2, C13.2, C14.2, C15.2, C16.1, C17.1, C18.2, C19.2, C20.2, C21.2, C22.2, C23.2, C24.2, C25.2, C26.2, D1.1 (K), D2.1 (A), D12.1 (K), D13.1 (K), J1.5 (GND), J2.6, J3.2, J4.4, J5.2, J6.3, J7.4, J8.2, J11.2, J12.2, J13.2, J14.1, J15.6 (VSS), J15.9 (SHIELD), J16.3, R15.1, SW1.1, SW2.1, SW3.2, U1.1 (GND), U2.2 (GND), U3.2 (GND), U4.2 (GND), U5.9 (GND), U6.1 (GND), U6.2 (GND), U6.9 (GND), U6.16 (GND), U7.4 (GND), U8.1 (GND), U8.7 (GND), X2.1 (GND), X2.40 (GND), X2.41 (GND), X2.42 (GND), X2.43 (GND), X2.44 (GND), X2.45 (GND), X2.46 (GND), X2.47 (GND), X2.48 (GND), X2.49 (GND); also elsewhere on the board
IRQ1: U6.5 (DIO0), X2.15 (IO3); also elsewhere on the board
IRQ2: U6.6 (DIO1), X2.34 (IO41); also elsewhere on the board
IRQ3: U6.7 (DIO2), X2.35 (IO42); also elsewhere on the board
LED: R7.1, X2.5 (IO5); also elsewhere on the board
MISO: J2.5, X2.24 (IO47); also elsewhere on the board
MISO_LORA: U6.13 (MISO), X2.21 (IO13); also elsewhere on the board
MISO_SD: J15.7 (DAT0), R19.2, X2.30 (IO37); also elsewhere on the board
MOSI: J2.4, X2.26 (IO45); also elsewhere on the board
MOSI_LORA: U6.14 (MOSI), X2.19 (IO11); also elsewhere on the board
MOSI_SD: J15.3 (CMD), R17.2, X2.28 (IO35); also elsewhere on the board
unnamed: C16.2, R3.1
unnamed: C22.1, R4.1
unnamed: D1.2 (A), R1.2
unnamed: D8.2 (A), D9.1 (K), U5.2 (LED1)
unnamed: D10.2 (A), D11.1 (K), U5.3 (LED2)
unnamed: D8.1 (K), D9.2 (A), D10.1 (K), D11.2 (A), U5.4 (LED3)
unnamed: D12.2 (A), R5.2
unnamed: D13.2 (A), R7.2
unnamed: C10.1, J11.1, U2.1 (VI)
unnamed: C12.1, J12.1, U3.1 (VI)
unnamed: C14.1, J13.1, U4.1 (VI)
unnamed: J16.1, R11.1
unnamed: R6.2, SW3.1
unnamed: C4.1, D3.C, D17.C, U1.3 (VI)
unnamed: C11.1, D4.A, U2.3 (VO)
unnamed: C13.1, D5.A, U3.3 (VO)
unnamed: C15.1, D7.A, U4.3 (VO)
unnamed: R5.1, R6.1, U5.5 (KEY)
unnamed: L1.1, U5.7 (SW)
unnamed: R14.1, U8.2 (CSB)
unnamed: R15.2, U8.5 (SDO)
RELAY: R11.2, X2.6 (IO6); also elsewhere on the board
RESET: U6.4 (~RESET), X2.22 (IO14); also elsewhere on the board
RXD1: J7.3, X2.36 (RXD0); also elsewhere on the board
RXD2: J4.3, X2.11 (IO18); also elsewhere on the board
SCL: J3.4, J5.4, J8.4, R9.1, R12.1, U8.4 (SCK), X2.32 (IO39); also elsewhere on the board
SCLK: J2.3, X2.16 (IO46); also elsewhere on the board
SCLK_LORA: U6.12 (SCK), X2.20 (IO12); also elsewhere on the board
SCLK_SD: J15.5 (CLK), R18.2, X2.29 (IO36); also elsewhere on the board
SDA: J3.3, J5.3, J8.3, R8.1, R13.1, U8.3 (SDI), X2.31 (IO38); also elsewhere on the board
TXD1: J7.2, X2.37 (TXD0); also elsewhere on the board
TXD2: J4.2, X2.10 (IO17); also elsewhere on the board
USB_D+: D2.3 (K), J1.3 (D+), X2.14 (IO20); also elsewhere on the board
USB_D-: D2.4 (K), J1.2 (D-), X2.13 (IO19); also elsewhere on the board
VIN_IP: C17.2, D4.C, D5.C, D6.C, D7.C, R3.2, U5.1 (VCC)
VOUT_IP: C18.1, C19.1, C20.1, D17.A, J16.2, U5.8 (VOUT)
XTAL_32K_N: C7.2, X2.9 (IO16), Y1.4; also elsewhere on the board
XTAL_32K_P: C6.2, X2.8 (IO15), Y1.1; also elsewhere on the board

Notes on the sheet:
SPI Connector
The capacitance is calculated as follows: C6=C7=2(Cl - Cs) Where: Cl -> Load Capacitance Cs -> Stray Capacitance
The input voltage comes from two modules, the USB port and the IP5306 charging module output. Diodes are introduced to prevent backfeeding.
I2C1 Connector
The IP5306 produces an output supply of 5V
*Note When the SDO pin is pulled to ground, the address becomes 0x76, which is the default mode. When it is left floating or pulled to VCC, the address becomes 0x77.
Mounting Holes
USB Port
UART2 Connector(DAC)
Tx/Rx
433MHz
BME280 Atmospheric Pressure Module
SX1278 Ra-02 Module for Tx and Rx
Connectors
Temperature and Humidity Sensor module
By using one SX1278 LoRa module, we can achieve half-duplex communication, which implies the device can transmit/receive at any given time, but not simultaneously
An interface for connecting an external 5V single channel relay module breakout board. The 'RELAY' interface is connected to GPIO6 of the ESP32-S3 through a 1K resistor, which serves as a current-limiting resistor.
Analog Connector
Power Circuitry & Real Time Clock
I2C3 Connector
Relay Connector
NB: For the RTC clock source, the 32.768kHz oscillator implemented should have an Equivalent Series Resistance (ESR) of <= 70kohm to operate with the ESP32-S3-WROOM-1 chip.
RTC Clock Source
I2C2 Connector
For the CSB pin, when it is connected to VCC, the I2C mode is enabled. When it is connected to GND, the SPI mode is enabled. In this case, we are implementing I2C, thus CSB is pulled to VCC
Boot Button
UART1 Connector
SPI Interface implemented in place of SDMMC
The IP5306 module obtains input supply from a 12V solar panel, as well as supply from the USB port. The 12V from the panel is stepped down using the LM7805 module to 5V, which is the typical operating voltage for the IP5306 module. An additional interface is included to cater for additinal supply f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
The LEDs provide real-time status of charging and battery level
Voltage Regulator
Trade offs between SPI and SDIO: 1. SPI is easier to implement in firmware and is supported by Arduino SD library 2. SDIO is much faster than SPI, about 12.5-50Mbps, as opposed to SPI which only has about 1-4Mbps 3. SDIO has dedicated hardware on ESP32, minimizing CPU load, while SPI has higher CPU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
Onboard LED
Reset Button
ESP32-S3-WROOM-1-N16R8
Power LED
Indicates programming functionality
DHT11 Sensor Module
Solar Panel 1
IP5306 Battery Charging Circuit

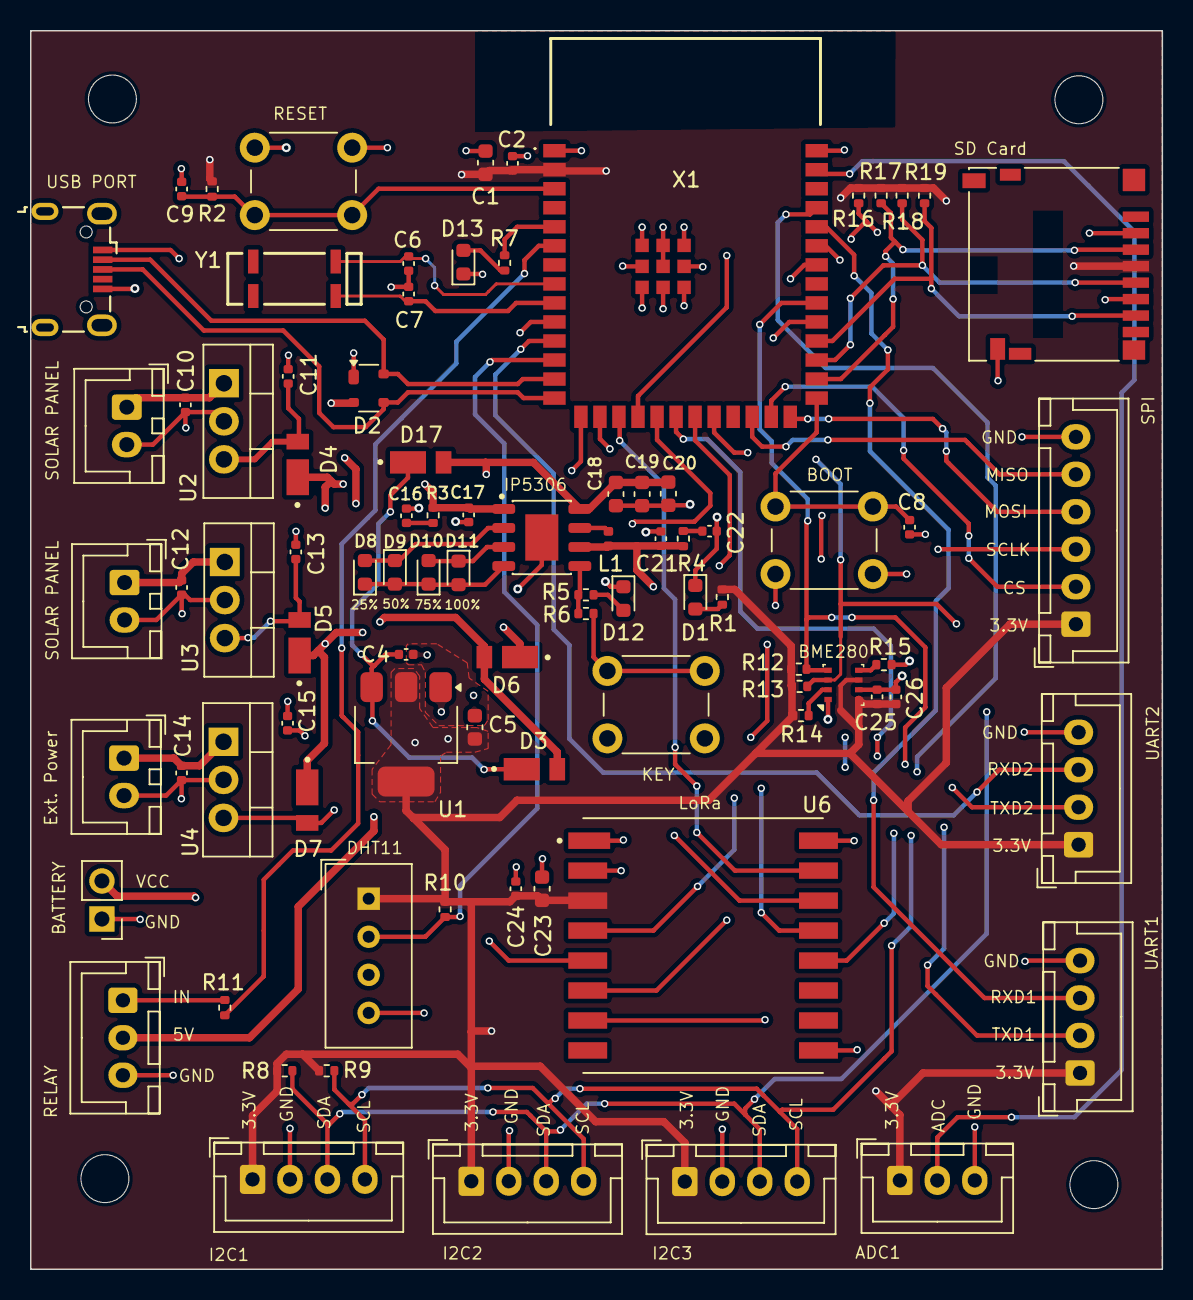
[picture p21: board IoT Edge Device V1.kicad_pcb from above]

Board: 4 copper layers, 75.5 x 82.7 mm, 90 parts (0 on the bottom side), 59 nets.

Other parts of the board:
X1: ESP32-S3-WROOM-1-N16R8; ESP32S3WROOM1N8R2

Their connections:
+3.3VREG: X1.2 (3V3); also elsewhere on the board
ADC: X1.39 (IO1); also elsewhere on the board
BOOT: X1.27 (IO0); also elsewhere on the board
CHIP_PU: X1.3 (EN); also elsewhere on the board
CS: X1.25 (IO48); also elsewhere on the board
CS_LORA: X1.17 (IO9); also elsewhere on the board
CS_SD: X1.18 (IO10); also elsewhere on the board
DHT_DATA: X1.12 (IO8); also elsewhere on the board
GND: X1.1 (GND), X1.40 (GND), X1.41 (GND), X1.42 (GND), X1.43 (GND), X1.44 (GND), X1.45 (GND), X1.46 (GND), X1.47 (GND), X1.48 (GND), X1.49 (GND); also elsewhere on the board
IRQ1: X1.15 (IO3); also elsewhere on the board
IRQ2: X1.34 (IO41); also elsewhere on the board
IRQ3: X1.35 (IO42); also elsewhere on the board
LED: X1.5 (IO5); also elsewhere on the board
MISO: X1.24 (IO47); also elsewhere on the board
MISO_LORA: X1.21 (IO13); also elsewhere on the board
MISO_SD: X1.30 (IO37); also elsewhere on the board
MOSI: X1.26 (IO45); also elsewhere on the board
MOSI_LORA: X1.19 (IO11); also elsewhere on the board
MOSI_SD: X1.28 (IO35); also elsewhere on the board
RELAY: X1.6 (IO6); also elsewhere on the board
RESET: X1.22 (IO14); also elsewhere on the board
RXD1: X1.36 (RXD0); also elsewhere on the board
RXD2: X1.11 (IO18); also elsewhere on the board
SCL: X1.32 (IO39); also elsewhere on the board
SCLK: X1.16 (IO46); also elsewhere on the board
SCLK_LORA: X1.20 (IO12); also elsewhere on the board
SCLK_SD: X1.29 (IO36); also elsewhere on the board
SDA: X1.31 (IO38); also elsewhere on the board
TXD1: X1.37 (TXD0); also elsewhere on the board
TXD2: X1.10 (IO17); also elsewhere on the board
USB_D+: X1.14 (IO20); also elsewhere on the board
USB_D-: X1.13 (IO19); also elsewhere on the board
XTAL_32K_N: X1.9 (IO16); also elsewhere on the board
XTAL_32K_P: X1.8 (IO15); also elsewhere on the board
